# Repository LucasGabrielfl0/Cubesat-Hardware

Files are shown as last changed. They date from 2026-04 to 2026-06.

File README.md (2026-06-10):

<h1 align="center"> ODYSSEY-HARDWARE</h1>

<p align="center">
  Repository for all the structural and electronic hardware for the ODYSSEY 2U CubeSat Prototype
</p>

<p align="center">


</p>

## Main
<p align="center">

ODYSSEY_Main_PCB
</p>

## Battery
<p align="center">


</p>

## EPS
<p align="center">


</p>

## Frame and Structure for Reaction Wheels
<p align="center">
Frame_noFront
Frame_and_Tree
</p>

## 🔗 Other Repositories in this Project
Here are the links for all the other repositores within this project
| Repository | Description |
|---|---|
| [ODYSSEY-CubeSat](https://github.com/LucasGabrielfl0/Cubesat-ODYSSEY) | Embedded flight software for the CubeSat, from communications to the 3 axys attitude control system|
| [CubeSat-GroundStation](https://github.com/LucasGabrielfl0/Cubesat-GroundStation) | Embedded software responsible for communication with the satellite. |
| [CubeSat-Dashboard](https://github.com/LucasGabrielfl0/Cubesat-Dashboard) | Desktop interface for telemetry visualization and command transmission. |

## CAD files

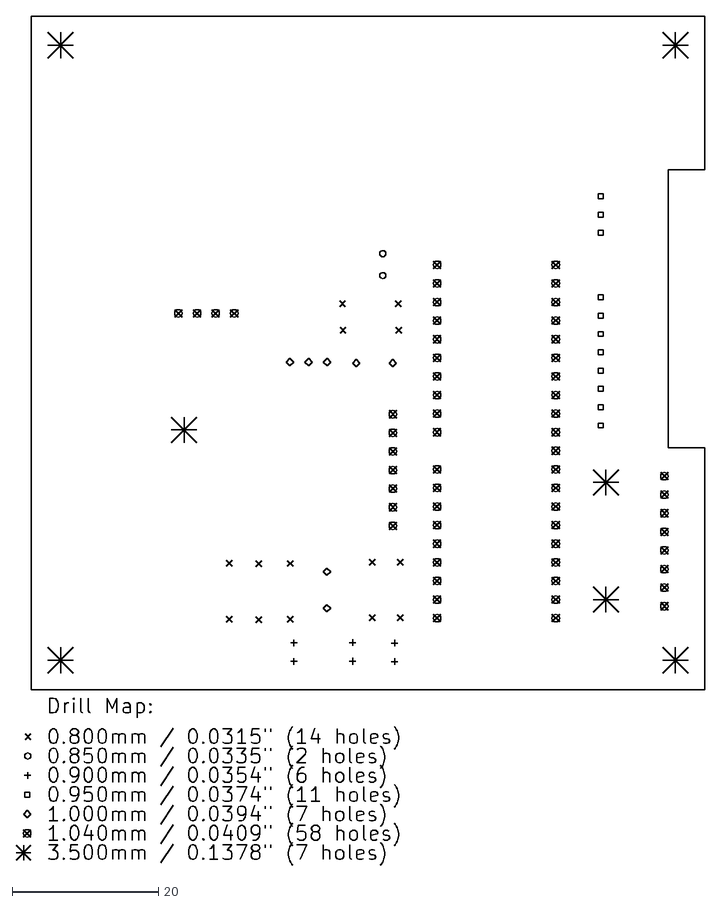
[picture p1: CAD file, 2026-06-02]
CubeSat-Main/Fabrication/GERBER/CubeSat_Main-drl_map.dxf
94.0 x 116.0

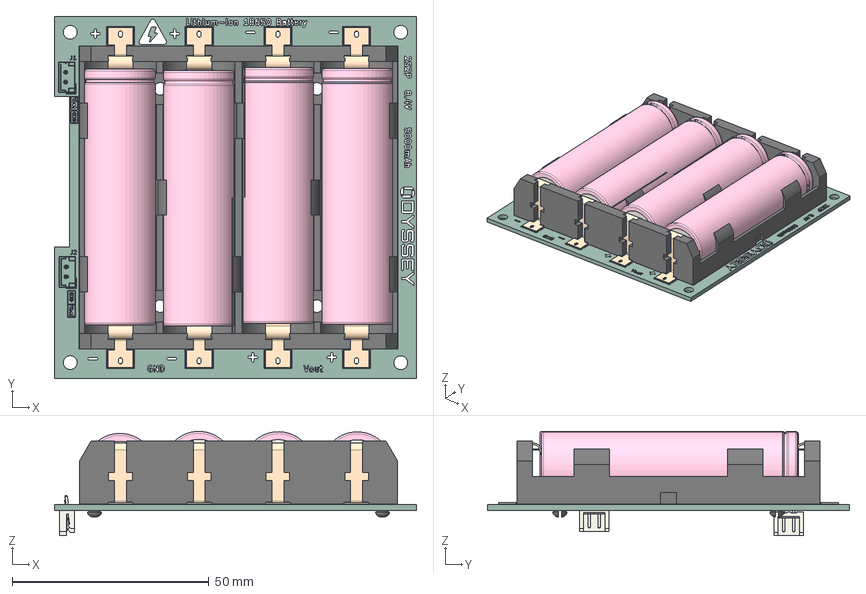
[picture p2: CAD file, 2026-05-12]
CubeSat-Battery/CubeSat_Battery.step
92.0 x 92.0 x 26.5 mm
Hold_18650_Con_smd x 8
Hold_18650-4p_smd
18650 v4 v1 x 4
JST_EH_B2B-EH-A_1x02_P2.50mm_Vertical x 2
CubeSat_Battery_silkscreen
CubeSat_Battery_PCB

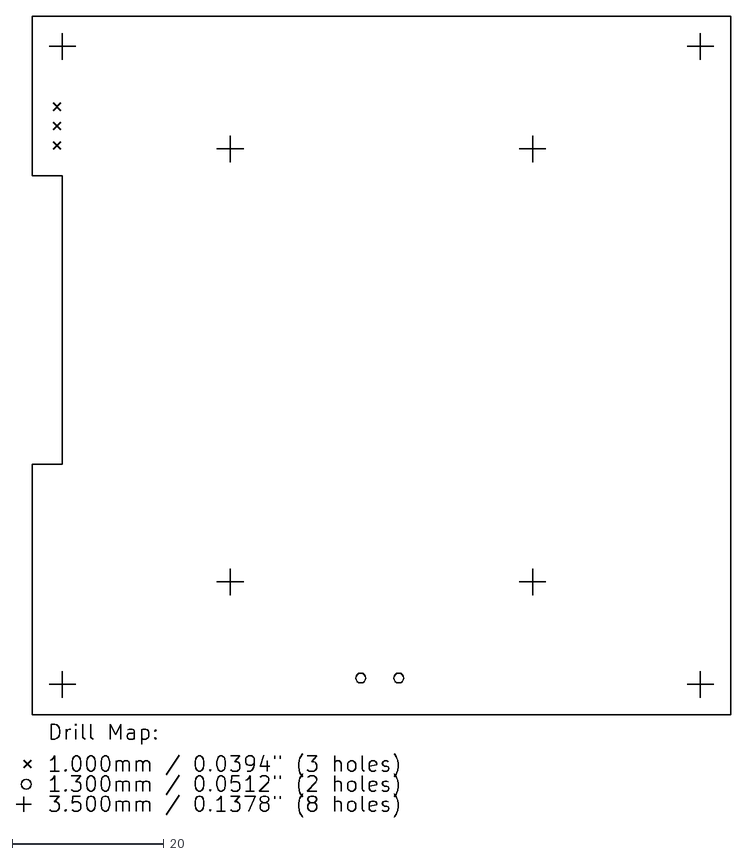
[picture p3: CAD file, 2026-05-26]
CubeSat-Battery/Fabrication/DRILL/CubeSat_Battery-drl_map.dxf
94.1 x 105.5

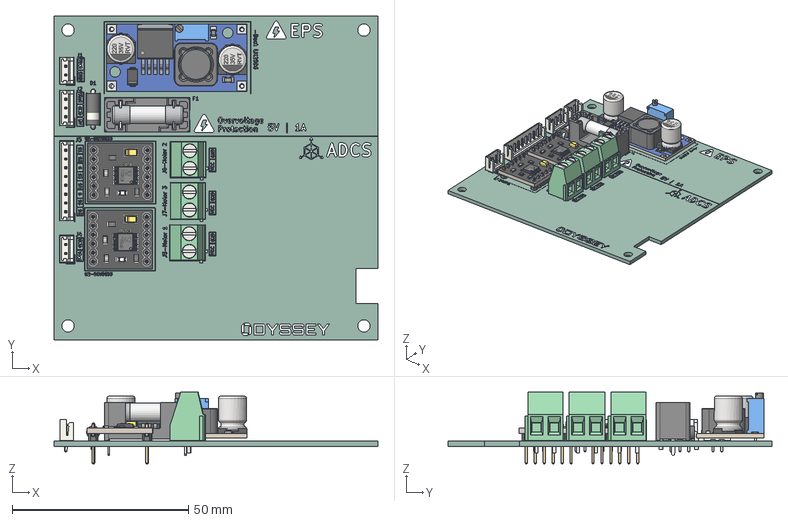
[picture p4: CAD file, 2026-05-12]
CubeSat-EPS-ADCS/CubeSat_EPS_ADCS.step
92.0 x 92.0 x 20.4 mm
placa x 2
TSSOP_cuerpo_1.2h x 2
TSSOP_pin_6.6 x 4
PIN_macho_1x6 x 4
T494A x 2
C0805_060 x 4
R0805 x 4
housing x 2
marking x 4
cover x 2
base_2 x 2
base x 2
TerminalBlock_Phoenix_MKDS-1,5-2-5.08_1x02_P5.08mm_Horizontal
FRONT x 2
JST_EH_B2B-EH-A_1x02_P2.50mm_Vertical x 2
JST_EH_B3B-EH-A_1x03_P2.50mm_Vertical
TerminalBlock_Phoenix_MKDS-1,5-2_1x02_P5.00mm_Horizontal x 2
board
capacitor
CAPSMD220-35 x 2
Diode SMA
inductor
lm2596
resistor
trimpot
D_5W_P10.16mm_Horizontal
JST_EH_B8B-EH-A_1x08_P2.50mm_Vertical
CubeSat_EPS_ADCS_silkscreen
CubeSat_EPS_ADCS_PCB

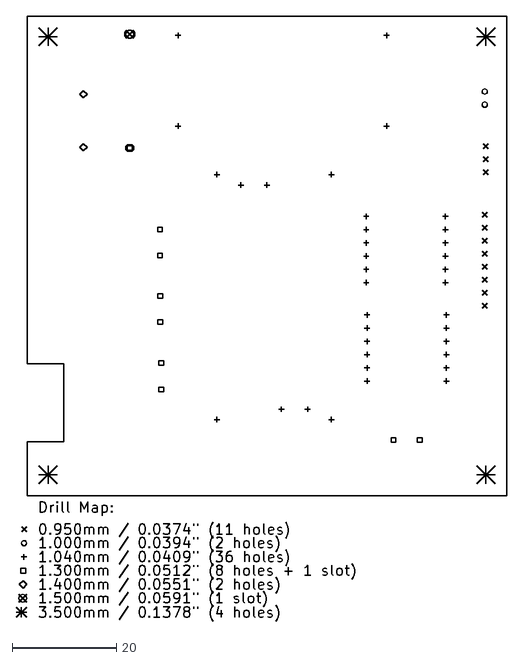
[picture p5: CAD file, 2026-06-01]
CubeSat-EPS-ADCS/Fabrication/GERBER/CubeSat_EPS_ADCS-drl_map.dxf
94.1 x 116.1

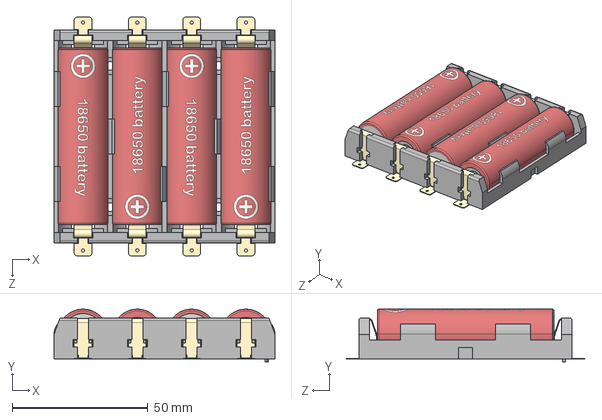
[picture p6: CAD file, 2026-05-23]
Kicad_Libraries/Models_3D/BATTERY_PACK_18650/4x18650 slot.STEP
81.4 x 19.4 x 87.9 mm

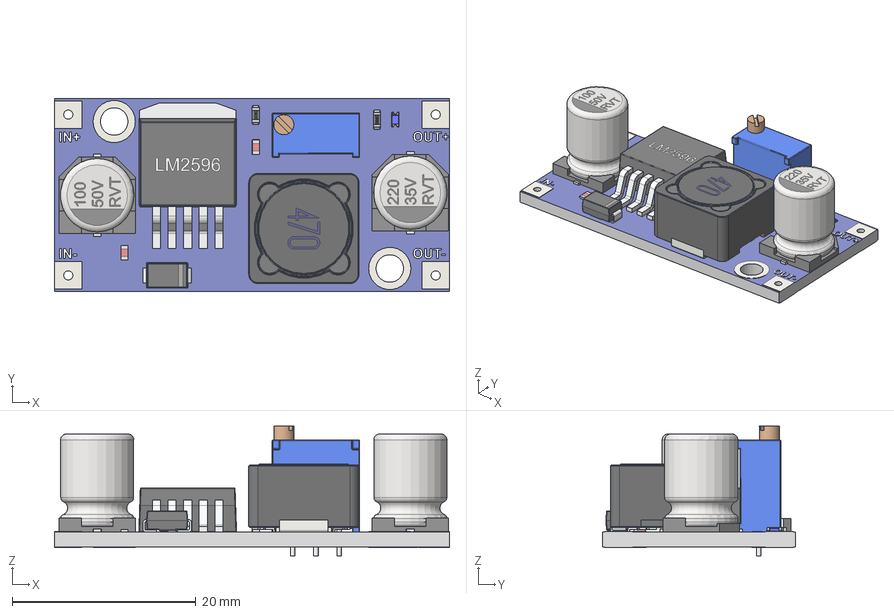
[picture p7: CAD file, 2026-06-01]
Kicad_Libraries/Models_3D/Buck_Converter/LM2596 DC-DC StepDown Converter v1.step
43.0 x 21.0 x 14.2 mm
Board v5
Trimpot 3296W v1
CDRH127_470M v1
CAPSMD220-35 v1
CAPSMD100-50 v1
TO-263BA v2
DO-214AC-DIOM5127X23N v1
Resistor 0603 v1
Resistor 0603 v1 (1)
CAP0603 v1
LED Blue SMD 0603 Würth 150060BS55040 v1
CAP0603 v1 (1)

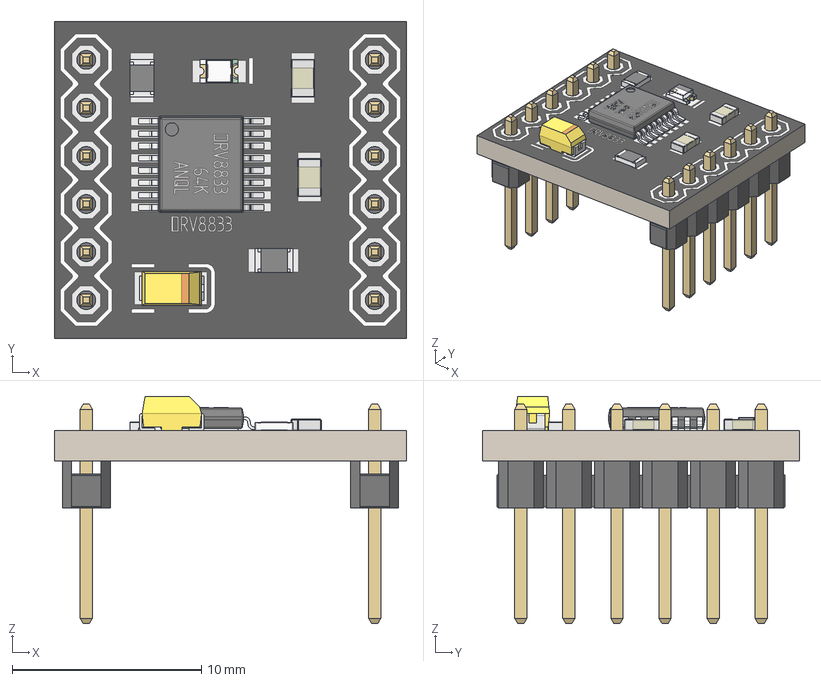
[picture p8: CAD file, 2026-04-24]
Kicad_Libraries/Models_3D/DRV8833/Modulo_DRV8833_A.stp
18.6 x 16.8 x 12.0 mm
placa
TSSOP_cuerpo_1.2h
TSSOP_pin_6.6 x 2
PIN_macho_1x6 x 2
T494A
C0805_060 x 2
R0805 x 2
housing
marking x 2
cover
base_2
base

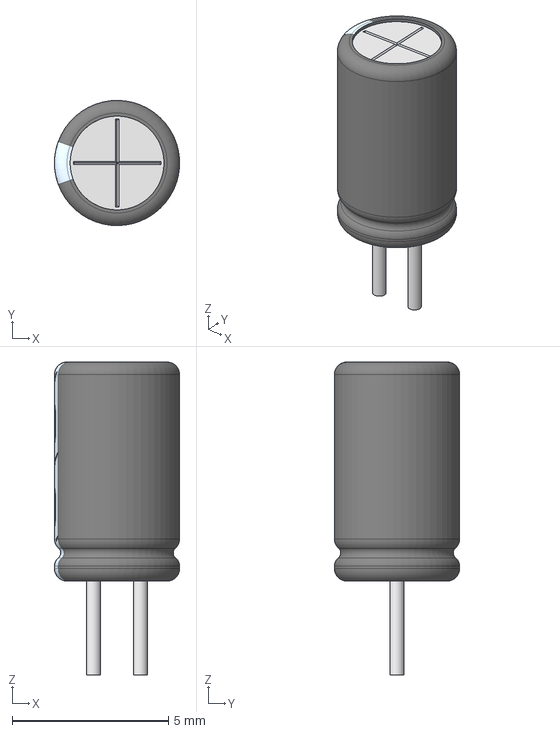
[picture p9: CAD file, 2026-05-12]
Kicad_Libraries/Models_3D/Electrolytic_Capacitor/ElCapVT-1.5-4x7-black.step
4.00 x 4.00 x 10.0 mm

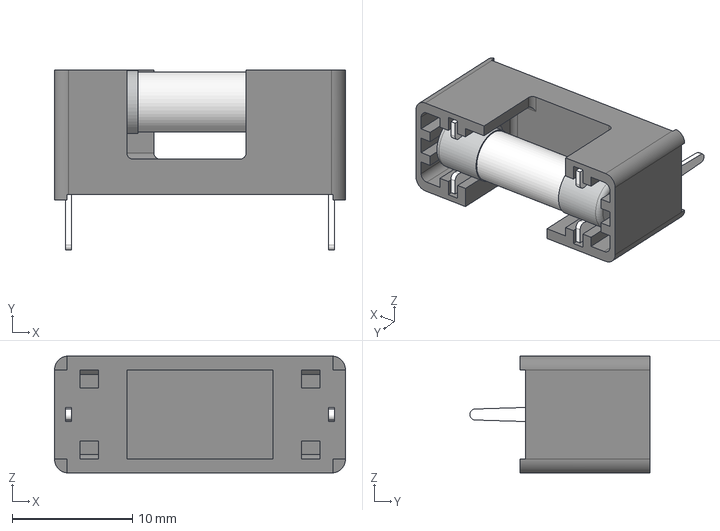
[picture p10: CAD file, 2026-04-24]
Kicad_Libraries/Models_3D/FUSE_4527/Fuse_FuseHolder_4527.step
24.2 x 15.0 x 9.70 mm
FRONT x 2

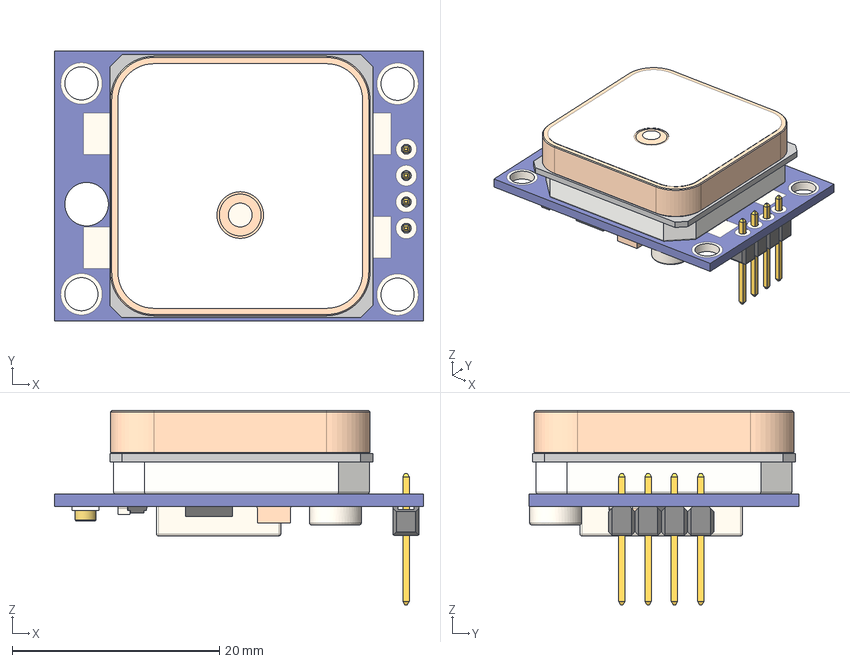
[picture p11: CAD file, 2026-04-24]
Kicad_Libraries/Models_3D/GPS_NEO6M/GY-NEO6MV2-withAnt v7.step
35.6 x 26.1 x 19.0 mm
Pin Header 1x4 TH Pitch 2.54mm

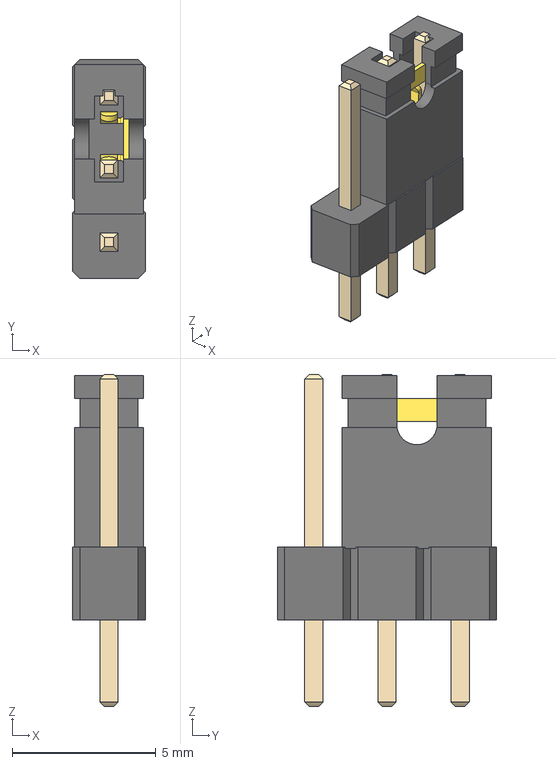
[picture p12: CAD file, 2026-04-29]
Kicad_Libraries/Models_3D/Header_Pins/PinHeader_1x03_P2.54mm_Vertical_Jumper.step
2.54 x 7.62 x 11.5 mm

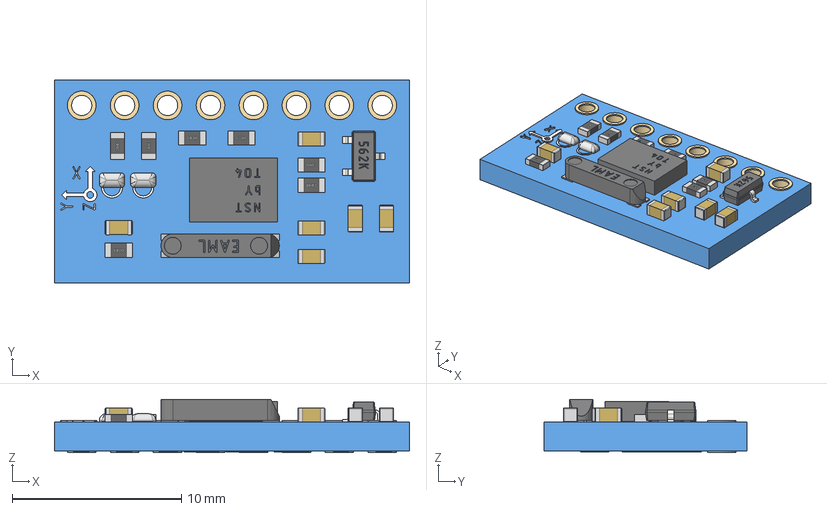
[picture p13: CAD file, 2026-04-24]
Kicad_Libraries/Models_3D/IMU_BNO055/GY-BNO055.stp
21.0 x 12.0 x 3.15 mm
0603 Resistor x 7
0603 Capacitor x 6

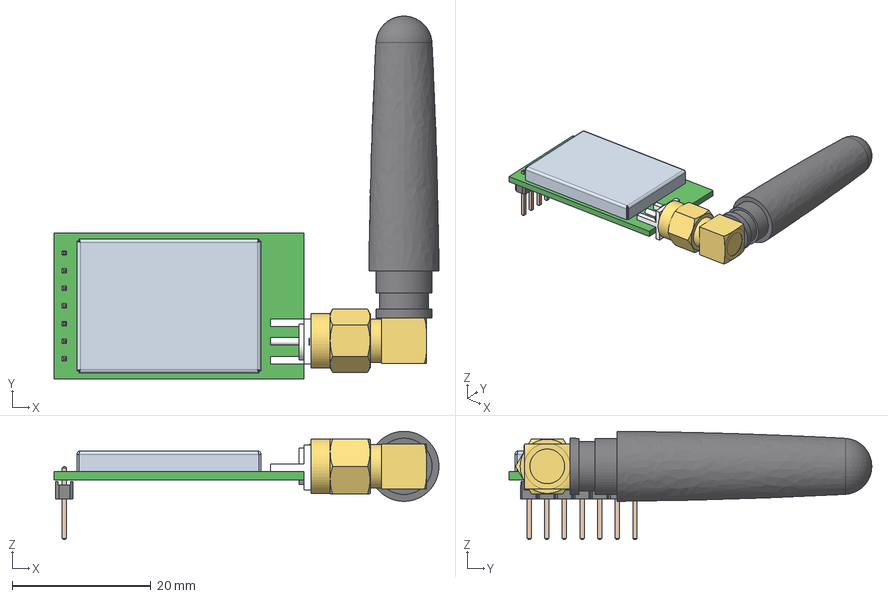
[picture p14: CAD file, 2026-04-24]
Kicad_Libraries/Models_3D/RADIO_EBYTE_E220_900T22D/E220_Antennav5.step
55.4 x 52.2 x 15.6 mm
Pin x 7
Spin
Base
PCB
RFbox
Antenna - Lambdoid - LWC-GSM-RD-RA-SMA-PLUG-02

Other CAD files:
Kicad_Libraries/Models_3D/STM32F411CEU6/BlackPill_F401v31.step
Kicad_Libraries/Models_3D/Switch/ss12d06.stp
Kicad_Libraries/Models_3D/Buck_Converter/XL4015 StepDown DC-DC 5A (CC-CV) v1.step
Kicad_Libraries/Models_3D/BATTERY_PACK_18650/18650 v4.step
Kicad_Libraries/Models_3D/BATTERY_PACK_18650/18650_2S_Holder.STEP
Kicad_Libraries/Models_3D/BATTERY_PACK_18650/BLM Blossom Electronics STM THM FOR 18650 Battery Holder With Battery V1.2.STEP
Kicad_Libraries/Models_3D/BATTERY_PACK_18650/Battery18650_2S.step
Kicad_Libraries/Models_3D/BATTERY_PACK_18650/BatteryPack_4S.step
Kicad_Libraries/Models_3D/BATTERY_PACK_18650/Hold_18650-4p_smd.stp
Kicad_Libraries/Models_3D/Buck_Converter/LM2596 DC-DC Buck Converter Module.stp
Kicad_Libraries/Models_3D/Electrolytic_Capacitor/0.22uF 50V electr 5 x11mm -P.diameter 2.5 mm-Black-White.stp
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

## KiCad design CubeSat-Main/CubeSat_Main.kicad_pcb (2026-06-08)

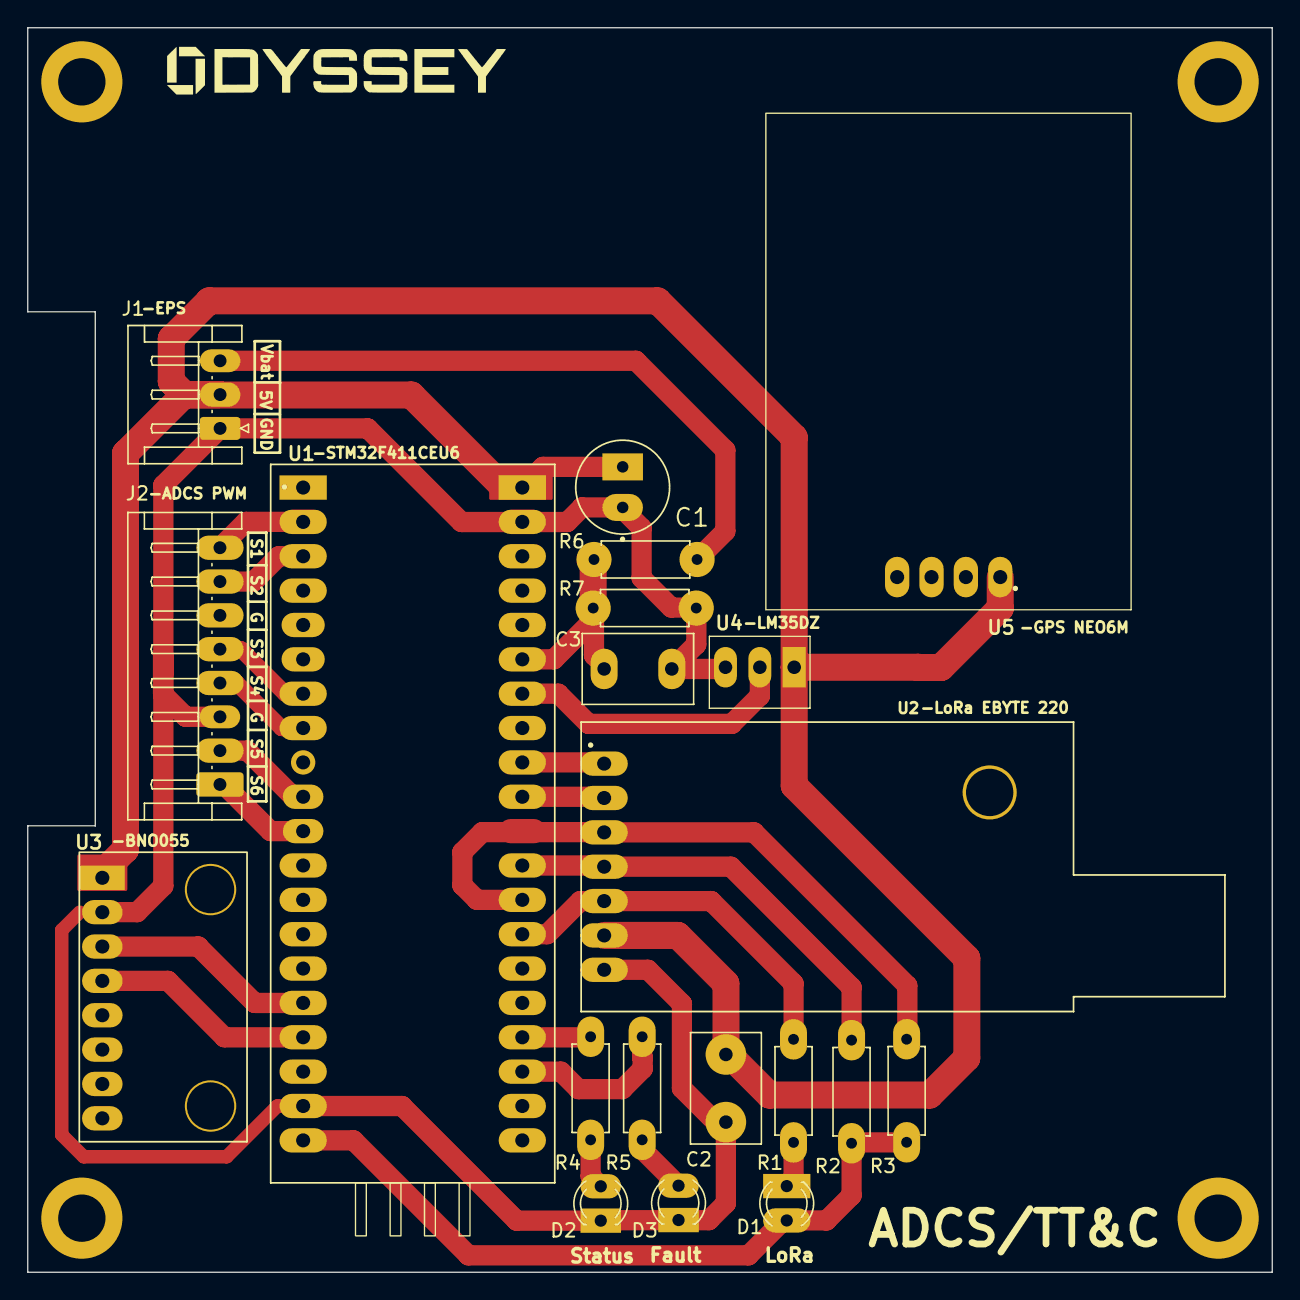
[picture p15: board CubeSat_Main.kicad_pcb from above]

Board: 2 copper layers, 92.0 x 92.0 mm, 20 parts (0 on the bottom side), 24 nets.

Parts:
C1: 22uF; Cap_Electrolytic
C2, C3: 0.1uF; C_Disc_D8.0mm_W5.0mm_P5.00mm
D1, D3: LED; LED_D3.0mm
D2: LED_Faul; LED_D3.0mm
J1: Conn_01x03_Pin; JST_EH_S3B-EH_1x03_P2.50mm_Horizontal
J2: Conn_01x08_Socket; JST_EH_S8B-EH_1x08_P2.50mm_Horizontal
R1, R3, R7: 4.7K; R_Axial_DIN0207_L6.3mm_D2.5mm_P7.62mm_Horizontal
R2: 4.7k; R_Axial_DIN0207_L6.3mm_D2.5mm_P7.62mm_Horizontal
R4, R5: 1K; R_Axial_DIN0207_L6.3mm_D2.5mm_P7.62mm_Horizontal
R6: 10K; R_Axial_DIN0207_L6.3mm_D2.5mm_P7.62mm_Horizontal
U1: STM32F411CEU6 - BlackPill; STM32F411CEU_BlackPill
U2: LORA E220-900T22D; LORA-E220-900T22D
U3: BNO055
U4: LM35-LP; LM35DZ
U5: GPS_NEO6M

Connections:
BNO055_SCL: U1.45 (PB8), U3.3 (SCL\RX)
BNO055_SDA: U1.46 (PB9), U3.4 (SDA\TX)
E220_AUX: R1.1, U1.11 (PA1), U2.5 (AUX)
E220_M0: U1.16 (PA6), U2.1 (MO)
E220_M1: U1.15 (PA5), U2.2 (M1)
E220_RX: R3.1, U1.12 (PA2), U1.14 (PA4), U2.3 (RXD)
E220_TX: R2.1, U1.13 (PA3), U2.4 (TXD)
GND: C1.2, C2.1, C3.1, D2.1 (K), D3.1 (K), J1.1, J2.3, R7.2, U1.23 (GND), U1.47 (GND), U2.7 (GND), U3.2 (GND), U4.3 (GND)
LED_BLUE: R4.1, U1.4 (PC15)
LED_RED: R5.1, U1.3 (PC14)
M1_PWM1: J2.8, U1.26 (PB13)
M1_PWM2: J2.7, U1.27 (PB14)
M2_PWM1: J2.5, U1.31 (PA10)
M2_PWM2: J2.4, U1.32 (PA11)
M3_PWM1: J2.2, U1.38 (PA15)
M3_PWM2: J2.1, U1.39 (PB3)
unnamed: D1.1 (K), R1.2
unnamed: D2.2 (A), R4.2
unnamed: D3.2 (A), R5.2
STM_3.3V: D1.2 (A), R2.2, R3.2, U1.48 (3V3)
Temp_ADC: U1.18 (PB0), U4.2 (V_{OUT})
VIN_5V: C1.1, C2.2, J1.2, U1.5V, U2.6 (VCC), U3.1 (VIN), U4.1 (+V_{S}), U5.1 (VCC)
Vbat_8.4V: J1.3, R6.1
Vbat_ADC: C3.2, R6.2, R7.1, U1.19 (PB1)

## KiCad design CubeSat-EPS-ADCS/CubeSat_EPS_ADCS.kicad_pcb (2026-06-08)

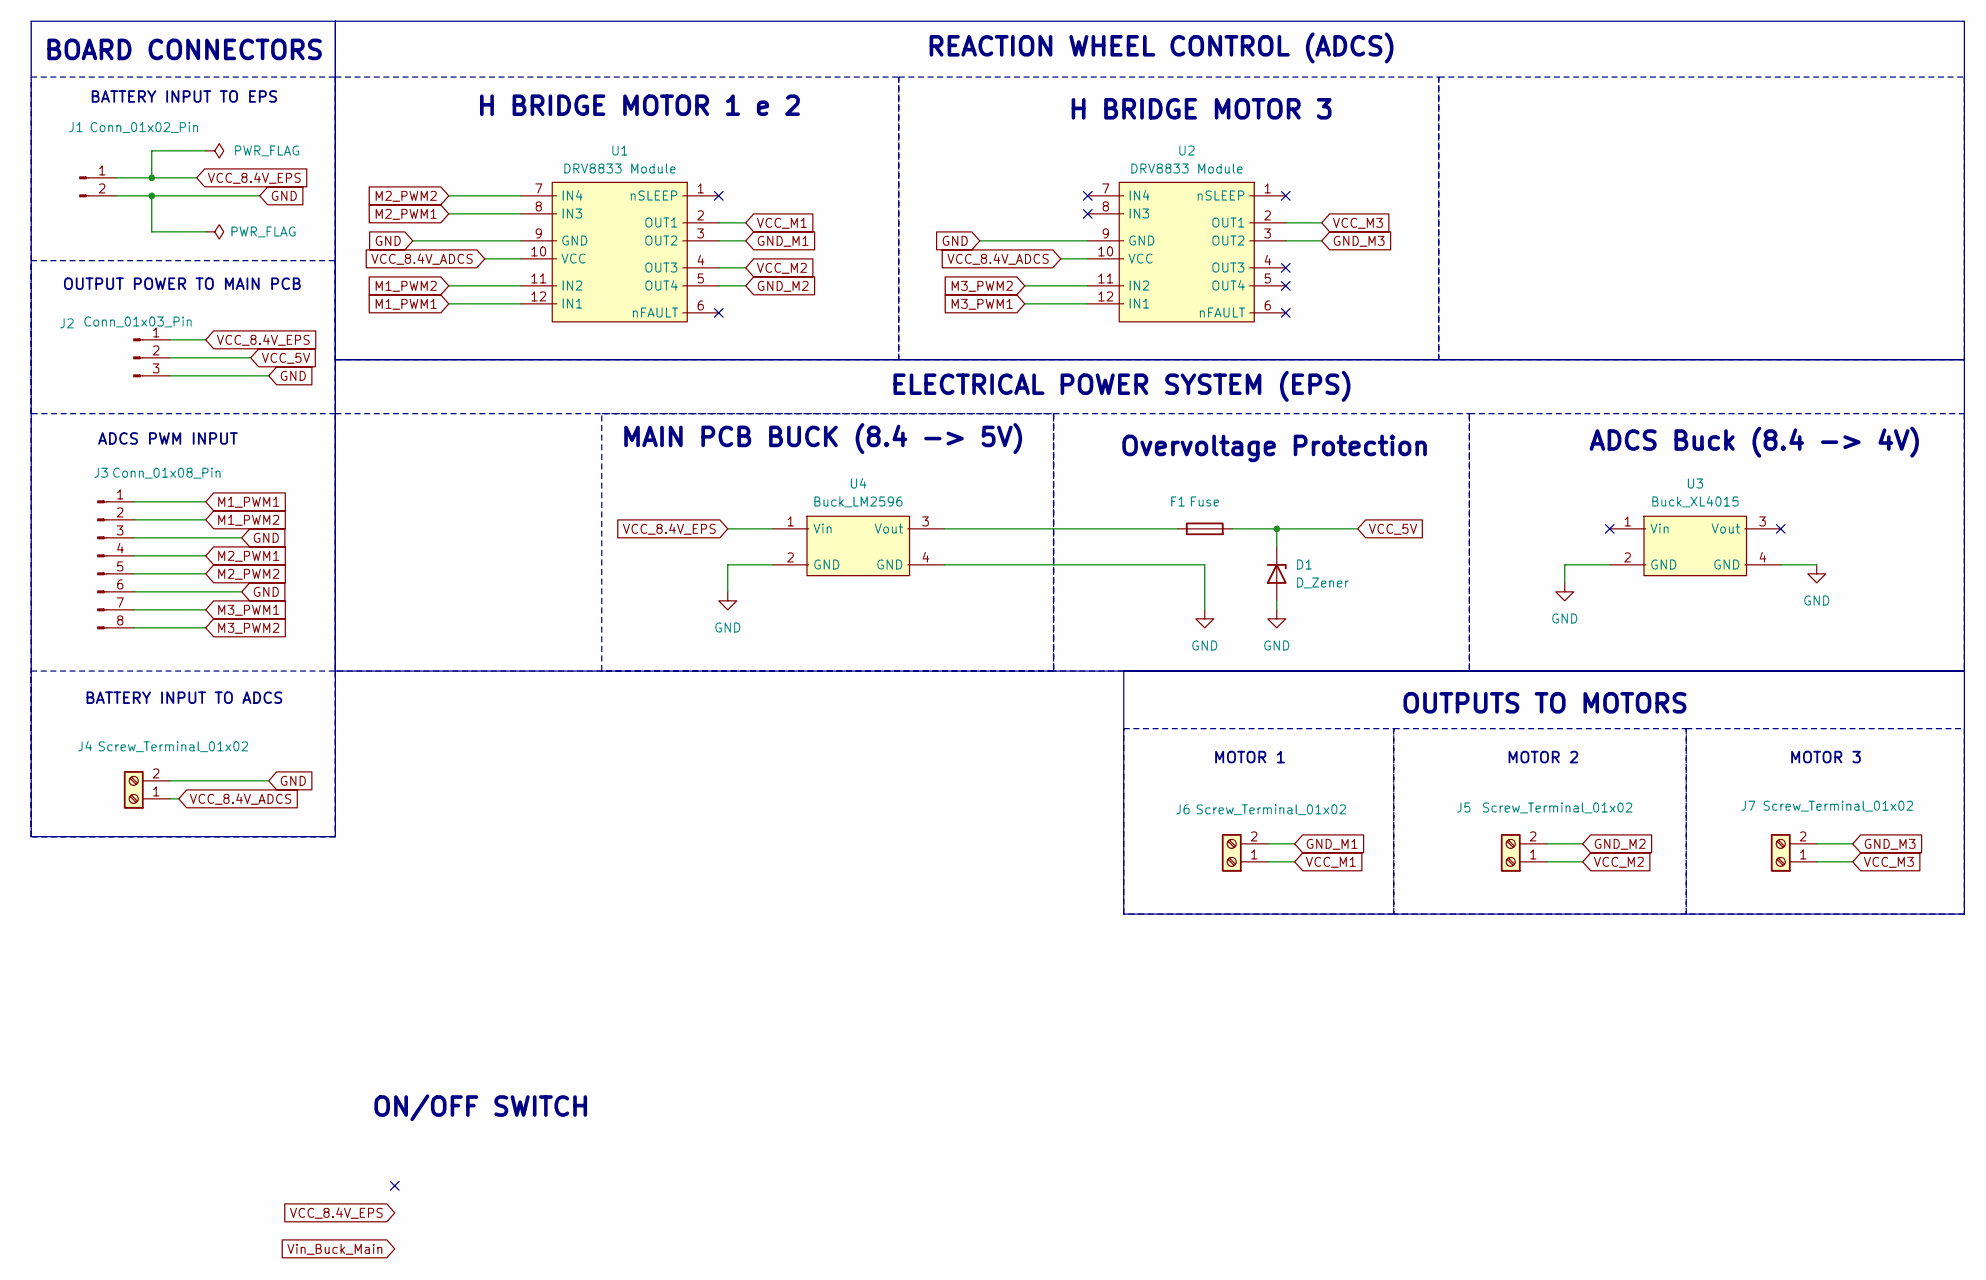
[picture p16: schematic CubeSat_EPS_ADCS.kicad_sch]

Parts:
D1: D_Zener; D_5W_P10.16mm_Horizontal
F1: Fuse; FUSE_4527
J1: Conn_01x02_Pin; JST_EH_B2B-EH-A_1x02_P2.50mm_Vertical
J2: Conn_01x03_Pin; JST_EH_B3B-EH-A_1x03_P2.50mm_Vertical
J3: Conn_01x08_Pin; JST_EH_B8B-EH-A_1x08_P2.50mm_Vertical
J4, J5, J6: Screw_Terminal_01x02; TerminalBlock_Phoenix_MKDS-1,5-2_1x02_P5.00mm_Horizontal
J7: Screw_Terminal_01x02; TerminalBlock_Phoenix_MKDS-1,5-2-5.08_1x02_P5.08mm_Horizont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
U1, U2: DRV8833 Module; DRV8833
U3: Buck_XL4015
U4: Buck_LM2596

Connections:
GND: D1.2 (A), J1.2, J2.3, J3.3, J3.6, J4.2, U1.9 (GND), U2.9 (GND), U3.2 (GND), U3.4 (GND), U4.2 (GND), U4.4 (GND)
GND_M1: J6.2, U1.3 (OUT2)
GND_M2: J5.2, U1.5 (OUT4)
GND_M3: J7.2, U2.3 (OUT2)
M1_PWM1: J3.1, U1.12 (IN1)
M1_PWM2: J3.2, U1.11 (IN2)
M2_PWM1: J3.4, U1.8 (IN3)
M2_PWM2: J3.5, U1.7 (IN4)
M3_PWM1: J3.7, U2.12 (IN1)
M3_PWM2: J3.8, U2.11 (IN2)
unnamed: F1.1, U4.3 (Vout)
VCC_5V: D1.1 (K), F1.2, J2.2
VCC_8.4V_ADCS: J4.1, U1.10 (VCC), U2.10 (VCC)
VCC_8.4V_EPS: J1.1, J2.1, U4.1 (Vin)
VCC_M1: J6.1, U1.2 (OUT1)
VCC_M2: J5.1, U1.4 (OUT3)
VCC_M3: J7.1, U2.2 (OUT1)

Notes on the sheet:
H BRIDGE MOTOR 1 e 2
BATTERY INPUT TO ADCS
REACTION WHEEL CONTROL (ADCS)
OUTPUT POWER TO MAIN PCB
ELECTRICAL POWER SYSTEM (EPS)
BATTERY INPUT TO EPS
OUTPUTS TO MOTORS
MAIN PCB BUCK (8.4 -> 5V)
ADCS PWM INPUT
Overvoltage Protection
BOARD CONNECTORS
ADCS Buck (8.4 -> 4V)
H BRIDGE MOTOR 3
MOTOR 2
ON/OFF SWITCH
MOTOR 3
MOTOR 1

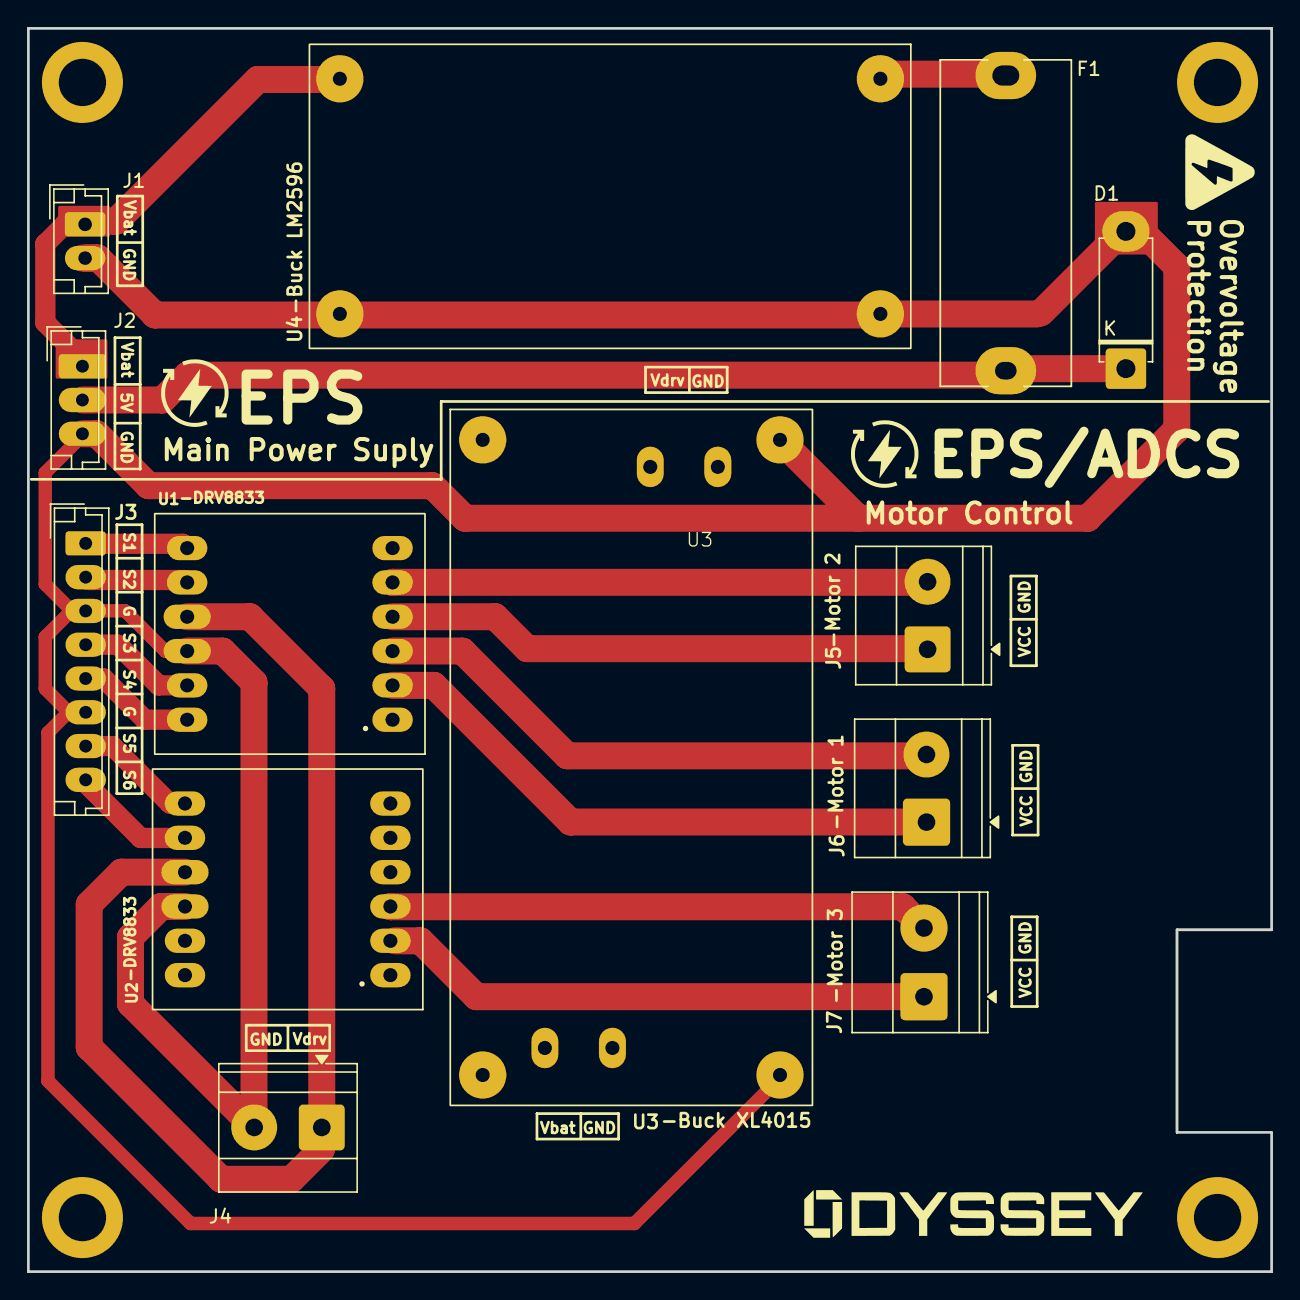
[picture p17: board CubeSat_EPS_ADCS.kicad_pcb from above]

Board: 2 copper layers, 92.0 x 92.0 mm, 13 parts (0 on the bottom side), 17 nets.

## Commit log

2026-04-24 First complete version of all the PCBs
    [18650 v4.step, 18650_2S_Holder.STEP, BLM Blossom Electronics STM THM FOR 18650 Battery Holder With Battery V1.2.STEP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]
2026-04-29 Mostly fine tuning the boards, also added capacitor for battery ADC
    [CubeSat_Battery.kicad_pcb, CubeSat_EPS_ADCS.kicad_pcb, CubeSat_EPS_ADCS.kicad_sch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]
2026-05-12 Changing the size of all traces to fit the 1 mm requirement of the draft PCB
    [0.22uF 50V electr 5 x11mm -P.diameter 2.5 mm-Black-White.stp, CubeSat_Battery.kicad_pcb, CubeSat_Battery.step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]
2026-05-14 final version of the 3 PCBs, minor size changes for the protoypes
    [CubeSat_Battery-B_Cu.gbr, CubeSat_Battery-B_Mask.gbr, CubeSat_Battery-B_Paste.gbr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]
2026-05-14 final changes
    [CubeSat_Battery-B_Cu.gbl, CubeSat_Battery-B_Mask.gbs, CubeSat_Battery-B_Paste.gbp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]
2026-05-14 new files
    [CubeSat_Battery-B_Cu.gbl, CubeSat_Battery-B_Cu.gbr, CubeSat_Battery-B_Mask.gbr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]
2026-05-14 version with the right hole setup
    [CubeSat_Battery.kicad_pcb]
2026-05-14 new files2
    [CubeSat_Battery-B_Cu.gbl, CubeSat_Battery-Edge_Cuts.gm1, CubeSat_Battery-F_Cu.gtl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]
2026-05-18 add new drill format
    [CubeSat_Battery-drl_map.dxf, CubeSat_Battery.kicad_pcb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]
2026-05-19 new origin placement
    [CubeSat_Battery-drl_map.dxf, CubeSat_Battery.kicad_pcb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]
2026-05-19 new origin placement + update all
    [CubeSat_Battery-B_Cu.gbl, CubeSat_Battery-Edge_Cuts.gbr, CubeSat_Battery-F_Cu.gtl]
2026-05-23 final changes in ALL 3 pcbs: mounting wholes config, and a few connector changes
    [4x18650 slot.STEP, CubeSat_Battery.kicad_pcb, CubeSat_Battery.kicad_sch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]
2026-05-25 last minute changes, adding kill swithc and backup buck converter for the motors
    [CubeSat_EPS_ADCS-drl_map.dxf, CubeSat_EPS_ADCS.kicad_pcb, CubeSat_EPS_ADCS.kicad_sch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]
2026-05-26 Add all most recent changes: EPS switch/extra buck update / Battery connector update
    [CubeSat_Battery-drl_map.dxf, CubeSat_Battery.kicad_pcb, CubeSat_Battery.step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]
2026-05-26 changing the size of the vias
    [CubeSat_Battery-drl_map.dxf, CubeSat_Battery.kicad_pcb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]
2026-05-26 Battery PCB connector update
    [CubeSat_Battery.kicad_pcb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]
2026-05-26 small changes
    [CubeSat_Battery.kicad_pcb, CubeSat_EPS_ADCS.kicad_pcb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]
2026-05-26 safety size change
    [CubeSat_EPS_ADCS.kicad_pcb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]
2026-06-01 new Main and EPS PCBs, all previous problems corrected, final version
    [CubeSat_Battery.kicad_pcb, CubeSat_Battery.kicad_sch, CubeSat_EPS_ADCS-drl_map.dxf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]
2026-06-01 adding the unused pin as smd, instead of just removing it
    [CubeSat_Main.kicad_pcb, CubeSat_Main.kicad_sch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]
2026-06-02 change in the GPS location, so it doesnt smash into its antenna
    [CubeSat_Main.kicad_pcb]
2026-06-02 small changes only
    [CubeSat_EPS_ADCS.kicad_pcb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]
2026-06-02 small changes in layout
    [CubeSat_EPS_ADCS.kicad_pcb, CubeSat_Main.kicad_pcb, CubeSat_Main.kicad_sch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]
2026-06-08 minor changes in the design
    [CubeSat_EPS_ADCS.kicad_pcb, CubeSat_Main.kicad_pcb, CubeSat_Main.kicad_sch]
